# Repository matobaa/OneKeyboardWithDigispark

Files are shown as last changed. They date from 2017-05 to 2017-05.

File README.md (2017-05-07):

# OneKeyboardを作る

DigiSparkを使うことで、USB接続のHID(Human Interface Device)を簡単に作成できます。100均のプッシュライトを改造して、キーひとつだけのキーボードデバイスを作ってみます。
なぜHIDか? 古き良き企業では、ソフトウェアやデバイスドライバをインストールするのに管理者の許可が必要であり、ドライバ不要のHIDになれるのはとても大きなメリットなのです。

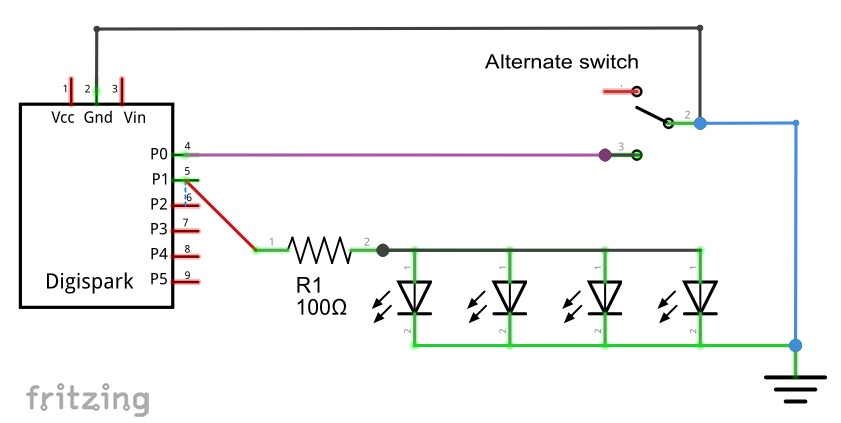
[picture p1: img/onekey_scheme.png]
scheme


## 開発環境の準備

### Arduino IDE のインストール

### Digisparkライブラリを組み込む

## ソフトウェア

1. Arduino IDE by DigiStomp
2. [スケッチ](prtScrnKey.ino)

#### オルタネートキー対応

ダイソータッチライトに内蔵されているスイッチは、押すごとにオンとオフが切り替わる、オルタネートタイプのスイッチなので、「現在から状態が変化したら」という条件で発火するようにした。判定処理はシンプルにかけた。

もし押したそのときだけオンになるモーメンタリタイプのスイッチを使う場合は、オンで発火したあとにオフになったことをもって次の判定に入る、ただしそのオンやオフはチャタリングではなく意図した操作である、といった処理を書かなくてはいけない。

#### SendKey関数

DigiKeyboard.SendKeyStroke だと指定したキーのあとに必ずキーオフのシーケンスを送出しているため、Alt+PrtSc だけを送出すると Windowsアプリでメニューを選択した状態が残ってしまう、という不具合があった。

そこで、SendKeyStroke からキーオフ送出部分を取り除いた関数を用意して、 Alt+ArtSc, Altのみ、キーオフ、という3段階で送出してみたところ、意図通りの機能となった。 Windowsに対してAltを併用するシーケンスを送出する場合の常套句なのではないだろうか。

## ハードウェア

### 今日の材料

1. [Digispark USB Development Board](http://digistump.com/products/1) (Clone; $2.29 @ eBay)
2. [ダイソー プッシュライト4LED](photo/0_pushlight.JPG) (&yen;108 @ daiso)
3. ダイソー MicroUSBケーブル (&yen;108 @ daiso)
4. 配線材を少々 (要らないLANケーブルをばらした)

### 工具リスト

1. ~~精密ドライバー +0 (ダイソーで6本入りのやつ)~~
2. グルーガン (ダイソー)　と　グルースティック　(ダイソー)
3. はんだごて　(ダイソー)　と　はんだ　(ダイソー)
4. ニッパ　(ダイソー)
5. バイス　(ダイソー)
6. やすり　(ダイソー)
7. 作業台　(壊れたテレビ台の天板を流用)
8. パイプ椅子　(ダイソー)

### 工作のようす

今日の材料であるダイソーのプッシュライト。単4電池3本でLEDを光らせるもの。裏側にはマグネットもついていておあつらえむきである。透明パーツの左側が支点となって、右端のスイッチを押し込むという構造。スイッチは押すとON、もう一回押すとOFFとなる、「オルタネート」タイプ。
ピンクの枠はカパッとはめてあるだけなので、手で引っ張るだけで簡単に外せる。透明のフタと銀色の板を外すだけで回路にたどりつける。

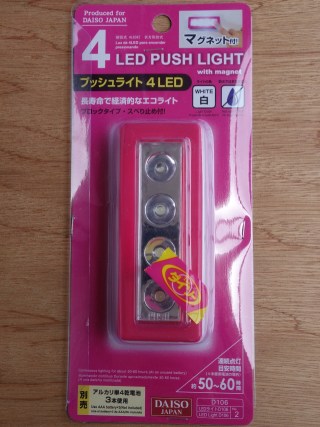
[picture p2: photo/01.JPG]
100-yen pushlight
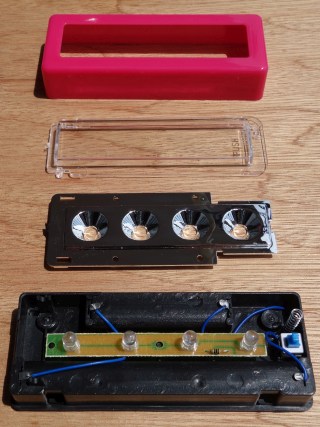
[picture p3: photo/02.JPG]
pushlight internal
 

LED基板も載せてあるだけなので、外しておく。青いワイヤは、バネの近くの一つはそのまま再利用するが、それ以外は外しておく。電池ケースの金属板は使わないので捨ててしまっていい。

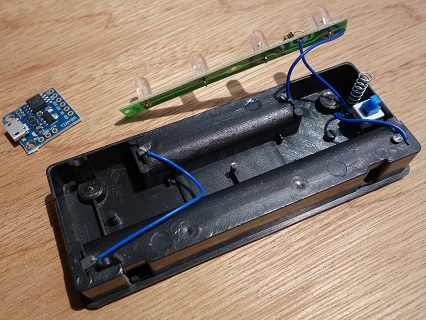
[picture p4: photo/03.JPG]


電池ケースの空きスペースにDigisparkがすっぽり収まる。邪魔になる黒い突起をひとつ、細い部分をニッパでちぎっておく。

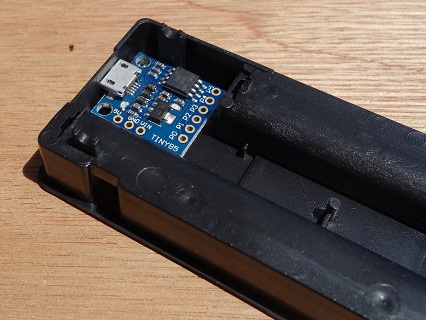
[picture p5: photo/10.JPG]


今回は裏返しにすることにした。完成イメージ、こんな感じかな。

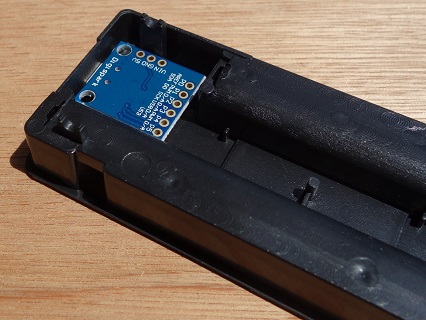
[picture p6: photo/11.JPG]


USBコネクタにあたる部分の黒い枠を、ニッパでちぎりとる。

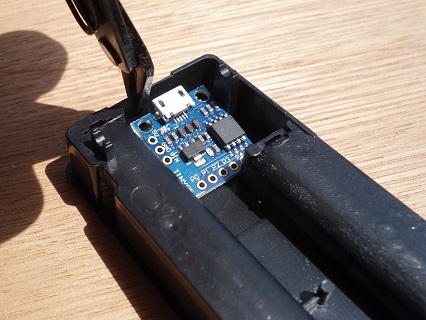
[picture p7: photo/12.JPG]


ちょっと切りすぎたけど気にしない。

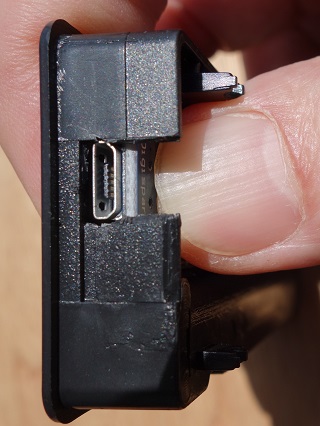
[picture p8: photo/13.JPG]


上からみると、これぐらい引っ込んでる。しかし、あつらえたようだ。

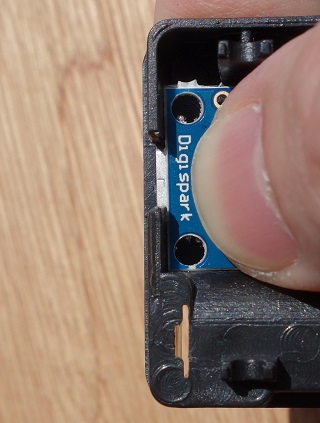
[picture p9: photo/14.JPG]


次はピンクの外枠を加工する。太陽に透かして見て、このへんかなあとあたりをつけて……

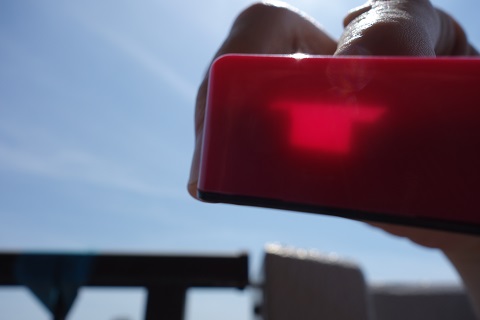
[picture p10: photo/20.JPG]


ピンバイスでゴリゴリと穴をあける。手回しなので、ちょっと根気がいる。

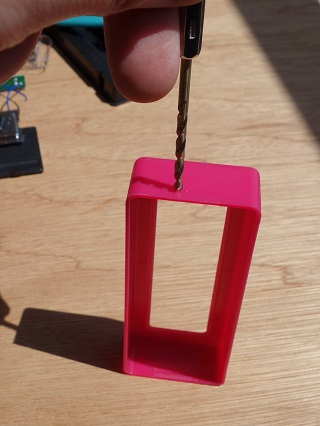
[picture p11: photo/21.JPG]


二つあけた。ずれてるけど気にしない。

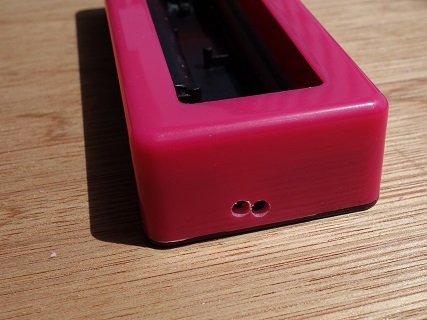
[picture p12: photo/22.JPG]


やすりを使って二つの穴をつなげて、MicroUSBコネクタが刺さるような穴にする。これもちょっと根気がいる。

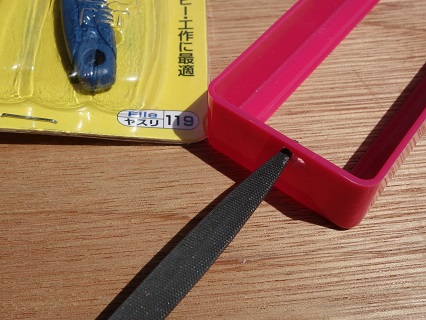
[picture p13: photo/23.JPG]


どうせコネクタで隠れるので、ちょっとくらいみっともなくても気にしない。

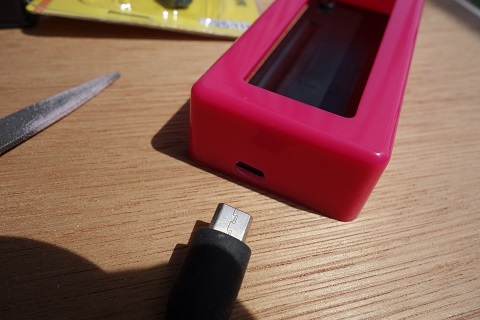
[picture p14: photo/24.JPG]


配線はこんなかんじで。
青い線は元のやつを再利用して、黒い線とねじり合わせてからスイッチの真ん中へ。黒い線の反対側は基板の下を通って左側のGNDへ。スイッチの端っこは赤い線でP0へ。基板の抵抗の足、もともと青い線がついてたところからP1へそれぞれはんだ付けする。

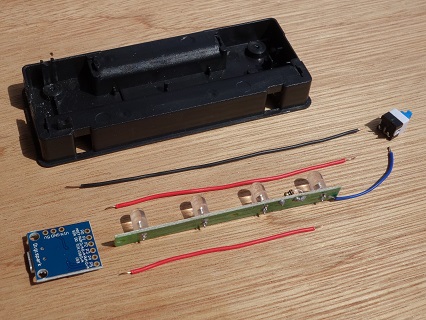
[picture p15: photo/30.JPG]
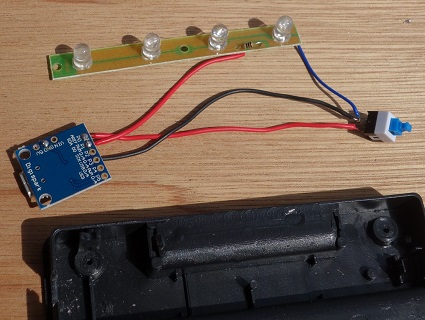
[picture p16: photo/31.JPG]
　

仮組みしてみて動作確認する。PCにつないでみて、2秒くらいしたらぴかあぁっと光って、押したらぴかぁ、もう一回押したらぴかぁとなればOK。

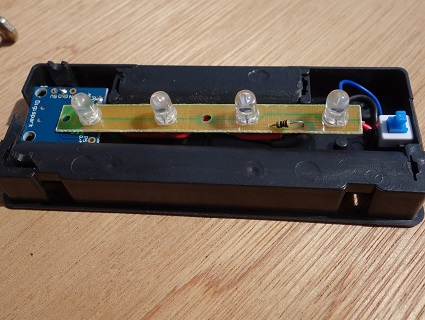
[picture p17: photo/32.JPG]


さて仕上げよう。グルーガンにグルースティックをセットしてあっためて……

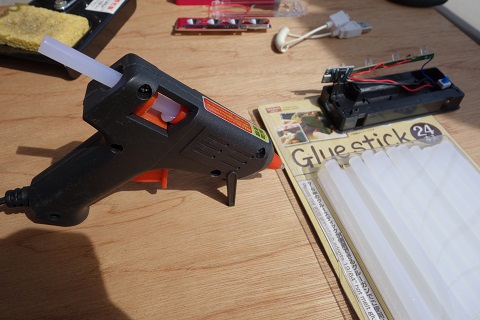
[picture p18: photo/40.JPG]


現物合わせにするので、ピンクのフタ側でUSBケーブルを刺して位置決めをした状態で……

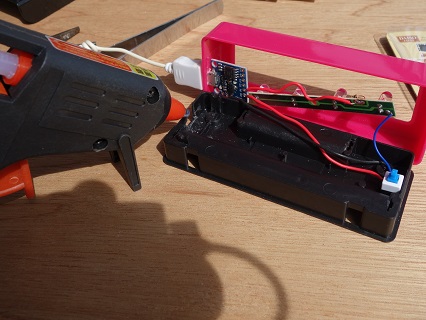
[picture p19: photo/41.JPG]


グルーをぶちゅぶちゅっと出して、冷めないうちにピンクのフタごとカパッとはめて、ちょっと冷めて固まったころに様子を見てみる。この写真はちょっとはみ出しちゃってる。ぺりっとはがして2回くらいやり直した。

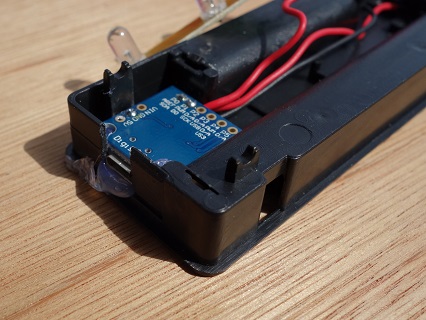
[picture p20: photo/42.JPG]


位置が決まったら、奥のカドのP0の近くあたりにも、グルーをぶちゅっとして固定しておく。

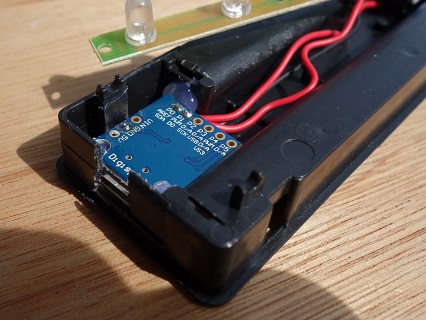
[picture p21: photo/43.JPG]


逆の手順で組み立てる。この写真には載ってないけれど、Digisparkの基板とLEDの基板が重なるところでショートしちゃうので、名刺くらいの紙を小さく切って2枚くらい挟む必要があった。

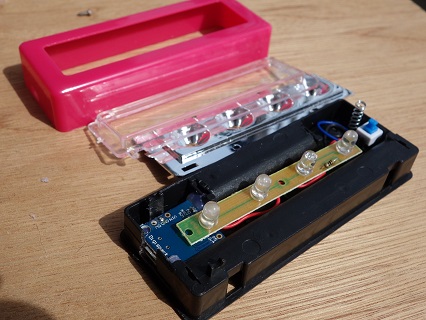
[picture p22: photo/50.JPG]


ピンクのフタをカパッとはめれば完成。

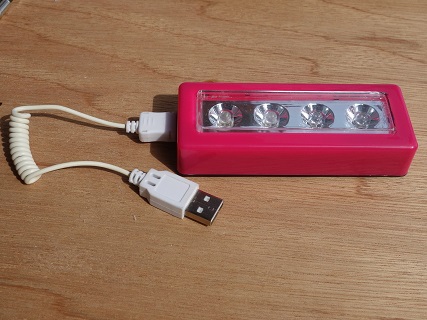
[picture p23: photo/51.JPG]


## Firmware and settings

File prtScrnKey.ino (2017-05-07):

// Boards manager URL: http://digistump.com/package_digistump_index.json
// Board: Digispark (Default 16.5MHz)

#include <DigiKeyboard.h>

int ledPin = 1;
int buttonPin = 0;
int groundPin = 5;
int fade = 6;

int lastButtonState;
int buttonState;
int brighthess;

void notify() {
  for (int brightness = 40; brightness > 0; brightness -= fade) {
    analogWrite(ledPin, brightness);
    DigiKeyboard.delay(30);
  }
  analogWrite(ledPin, 0);
}

void sendKey(byte keyStroke, byte modifiers) {
  while (!usbInterruptIsReady()) {
    usbPoll();
    _delay_ms(5);
  }
  memset(DigiKeyboard.reportBuffer, 0, sizeof(DigiKeyboard.reportBuffer));
  DigiKeyboard.reportBuffer[0] = modifiers;
  DigiKeyboard.reportBuffer[1] = keyStroke;
  usbSetInterrupt(DigiKeyboard.reportBuffer, sizeof(DigiKeyboard.reportBuffer));
}

void setup() {
  pinMode(ledPin, OUTPUT);
  pinMode(buttonPin, INPUT);
  digitalWrite(buttonPin, HIGH); // PULLUP
  pinMode(groundPin, OUTPUT);
  digitalWrite(groundPin, LOW);
  notify(); // ready
  buttonState = digitalRead(buttonPin);
}

void loop() {
  // detect alternate switch altered
  for (lastButtonState = buttonState; lastButtonState == buttonState; buttonState = digitalRead(buttonPin)) {
    DigiKeyboard.delay(100);
  }
  digitalWrite(buttonPin, HIGH); // KEEP PULLUP

  // send Key Strokes; see http://www.usb.org/developers/hidpage/Hut1_12v2.pdf#page=53
  sendKey(0, 0); // all key up
  sendKey(70, MOD_ALT_LEFT);  // Alt + Tab (43) // PrtSc 70
  sendKey(0, MOD_ALT_LEFT);   // Alt
  sendKey(0, 0); // all key up
  notify();
}
